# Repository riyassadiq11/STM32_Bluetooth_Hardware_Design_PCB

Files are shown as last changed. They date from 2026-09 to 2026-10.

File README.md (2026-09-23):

# STM32_Bluetooth_Hardware_Design_PCB
4‑layer PCB (49 × 24 mm, 1.6 mm) using STM32WB55CEU6 for Bluetooth. Features USB‑C with ESD protection, RF + U.FL antenna, SWD debug header, and SMPS power. Includes impedance‑controlled routing, custom footprint (DLF162500LT‑5028A1), 3D STEP models, and validated with ERC/DRC checks.

# 📡 STM32WB55 Bluetooth Hardware Design (KiCad, 4‑Layer)

## 📖 Project Overview
This project is a **4‑layer PCB design** using **STM32WB55CEU6 microcontroller** for Bluetooth communication.  
It integrates USB‑C interface, RF with U.FL antenna connector, SWD debug header, and regulated 3.3V supply.  
Custom footprints and 3D models were created to ensure accurate visualization and manufacturing readiness.

---

## 📐 PCB Specifications
- **Board size:** 49 mm × 24 mm  
- **Thickness:** 1.6 mm  
- **Layers:** 4‑layer stackup  
- **Copper Pour:**  
  - **Layer 1 (Front):** GND plane  
  - **Layer 2 (In1):** GND plane  
  - **Layer 3 (In2):** GND plane  
  - **Layer 4 (Bottom):** Power plane  
- **Impedance Control:**  
  - 50 Ω ±10% single‑ended microstrip (trace width 0.19 mm)  
  - 90 Ω ±10% differential microstrip (trace width 0.22 mm, spacing 0.15 mm)  

---

## 🔌 Schematic Explanation

### Power Supply & SMPS
- **MIC5365‑3.3 LDO regulator** converts USB 5V to 3.3V.  
- Multiple **decoupling capacitors (100nF)** placed near VDD pins.  
- **SMPS pins (VLXSMPS, SMPSLX, SMPSFB, VFBSMPS)** connected with inductors/capacitors for internal buck converter.  
- Provides efficient power delivery for RF and digital domains.
- This reduces power consumption compared to pure LDO mode.

**Working:**  
STM32WB55 uses an internal buck converter. VLXSMPS pin drives the inductor, SMPSFB senses feedback, and VFBSMPS stabilizes output.This lowers current draw and heat, especially important for battery‑powered designs.

---

### ESD Protection
- **USBLC6‑2SC6 diode array** protects USB D+ and D‑ lines.  
- Ensures compliance with USB 2.0 signal integrity while clamping high‑voltage spikes
- Prevents damage from static discharge when plugging/unplugging USB‑C.  

---

### SWD Debug Connection
- **SWD_CLK (PA14)** → Debug clock.  
- **SWD_DIO (PA13)** → Bidirectional data line.  
- **SWO (PB3)** → Trace output.  
- **NRST** → Reset line.  
- Connected via **Tag‑Connect header** for programming/debugging. 

---

### RF
- RF output routed through **matching network (L3, capacitors)**. - **DLF162500LT low‑pass filter** ensures clean 2.4–2.5 GHz band. - **U.FL coaxial connector** for external antenna.  
- Ground stitching vias improve impedance control and reduce noise.

**Working:**  
MCU generates Bluetooth RF signal → passes through matching network → filtered → sent to antenna. Impedance control (50 Ω single‑ended) ensures maximum power transfer and minimal reflection.

---

### USB‑C Interface
- USB‑C connector with **CC1/CC2 resistors** for orientation detection.  
- D+ / D‑ routed with **90 Ω differential impedance**.  
- Protected by ESD diodes.  
- VBUS feeds the LDO regulator.

---

### Peripherals
- **UART header** for communication/debugging.  
- **LED with resistor** for status indication.  
- **Push button** for Boot0/reset.  
- **Crystals:**  
  - HSE (32 MHz) → system clock.  
  - LSE (32.768 kHz) → RTC.  

---

## ✅ Design Validation
- **ERC check:** Successfully completed for schematic (no electrical rule errors).  
- **DRC check:** Successfully completed for PCB layout (no design rule violations).  

---

## ⚙️ How It Works
1. USB‑C provides 5V → LDO converts to 3.3V → SMPS stabilizes supply.  
2. MCU runs with external crystals for accurate timing.  
3. SWD header allows firmware flashing and debugging.  
4. Bluetooth RF routed through matching network + LPF → antenna.  
5. USB‑C handles data, UART header provides serial debug.  
6. ESD diodes protect USB lines, ground stitching reduces noise.  
7. LED shows status, push button controls Boot0/reset.  

---

## 🛠️ Skill Highlights
- KiCad schematic capture & 4‑layer PCB design  
- Custom footprint creation (DLF162500LT‑5028A1)  
- 3D STEP model integration (MCU, filter, crystal)  
- Impedance‑controlled routing (USB & RF)  
- SWD debug integration  
- USB‑C interface with ESD protection  
- RF matching & antenna connector design  
- ERC & DRC validation for schematic and PCB  
- Copper pour strategy (3 GND planes + 1 power plane)  
- Gerber/BOM/pick‑and‑place generation  
- Ground stitching & copper pour techniques

## Key Learnings:
- MCU & Debugging: Gained detailed knowledge of STM32WB55 pin functions, SWD interface, and MCU working principles.
- RF Engineering: Learned antenna integration, RF matching networks, and impedance‑controlled routing for Bluetooth signals.
- USB Integration: Implemented USB‑C interface with differential pair matching, controlled impedance, and ESD protection.
- Impedance Control: Calculated and applied trace width/spacing for 50 Ω single‑ended and 90 Ω differential pairs.
- PCB Stack‑Up: Understood layer stackup, core and prepreg materials (e.g., 2126), and their role in signal integrity.
- Manufacturing Readiness: Applied mounting holes, fiducial markers, and copper pour strategy (3 GND planes + 1 power plane).
- Routing Techniques: Learned via diameter selection, trace width/spacing rules, and applying specific constraints for USB and RF connections.
- Design Validation: Performed ERC and DRC checks to ensure error‑free schematic and PCB layout.

## 🖼️ Schematic

The schematic illustrates the complete STM32WB55CEU6 Bluetooth hardware design, including power supply (LDO + SMPS), USB‑C interface with ESD protection, SWD debug header, RF front‑end with matching network and U.FL antenna connector, and peripheral components (UART, LED, crystals, push button).  

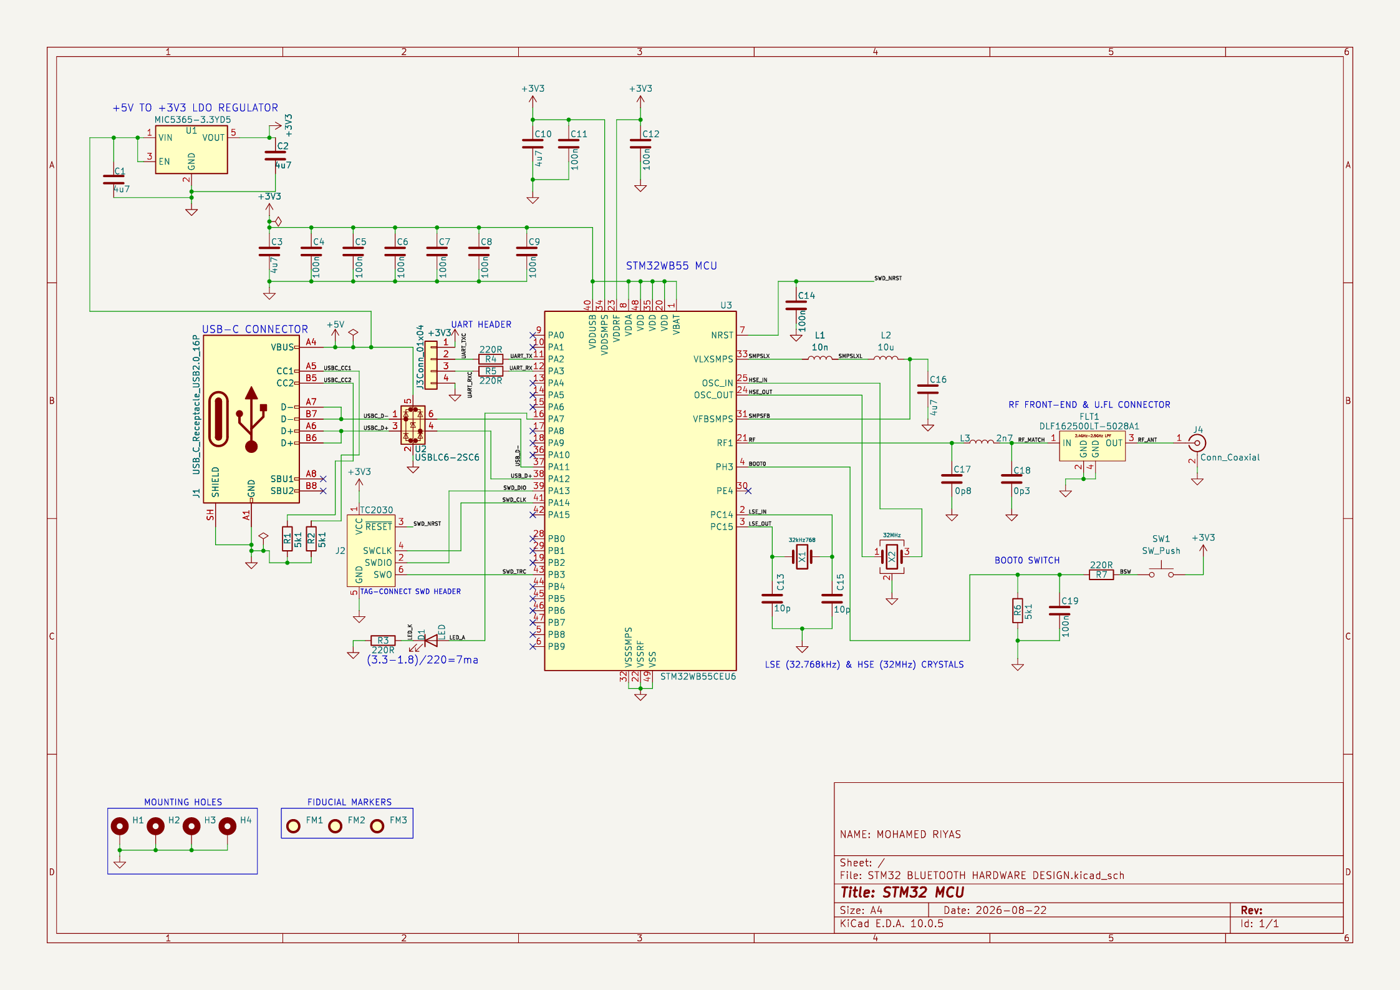
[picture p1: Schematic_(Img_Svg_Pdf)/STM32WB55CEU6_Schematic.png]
Schematic


## 🖼️ PCB Layout – Top Layer

The top layer layout shows the placement of STM32WB55CEU6, USB‑C connector, RF front‑end, SWD header, and supporting components.  
Silkscreen markings highlight pin labels and orientation for assembly.  
Copper pour on this layer is dedicated to the **GND plane**, ensuring stable return paths and reduced EMI.  

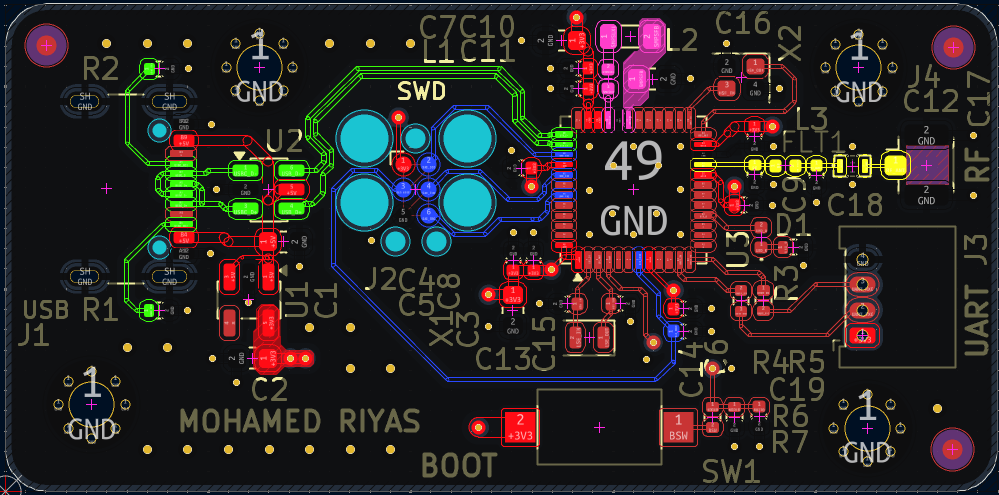
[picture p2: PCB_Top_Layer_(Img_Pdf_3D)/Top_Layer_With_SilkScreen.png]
Top Layer


## 🖼️ PCB Layout – Bottom Layer

The bottom layer layout highlights the routing of power planes and supporting traces.  
This layer is dedicated to the **power plane**, ensuring stable distribution of 3.3V and other supply rails across the board.  
It complements the three GND planes (Front, In1, In2) by providing a clean separation of power and ground, improving signal integrity and reducing noise.  

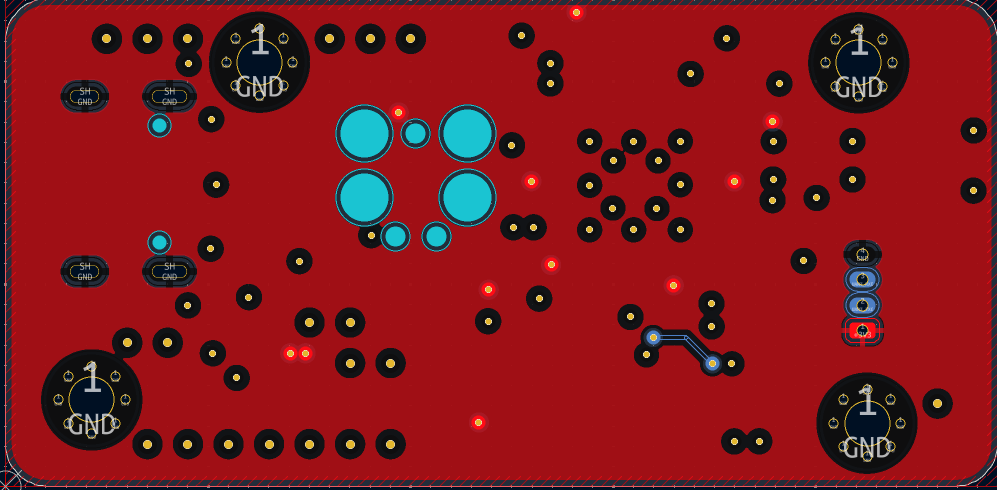
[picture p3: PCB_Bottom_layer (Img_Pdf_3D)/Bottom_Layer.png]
Bottom Layer


## 🖼️ 3D Views

The 3D views provide a realistic visualization of the PCB assembly.  
They include custom **STEP models** for the STM32WB55CEU6 microcontroller, the DLF162500LT‑5028A1 RF filter, and the 32.768 kHz crystal.  
These models ensure accurate mechanical alignment, proper component clearance, and a professional preview of the final board.  

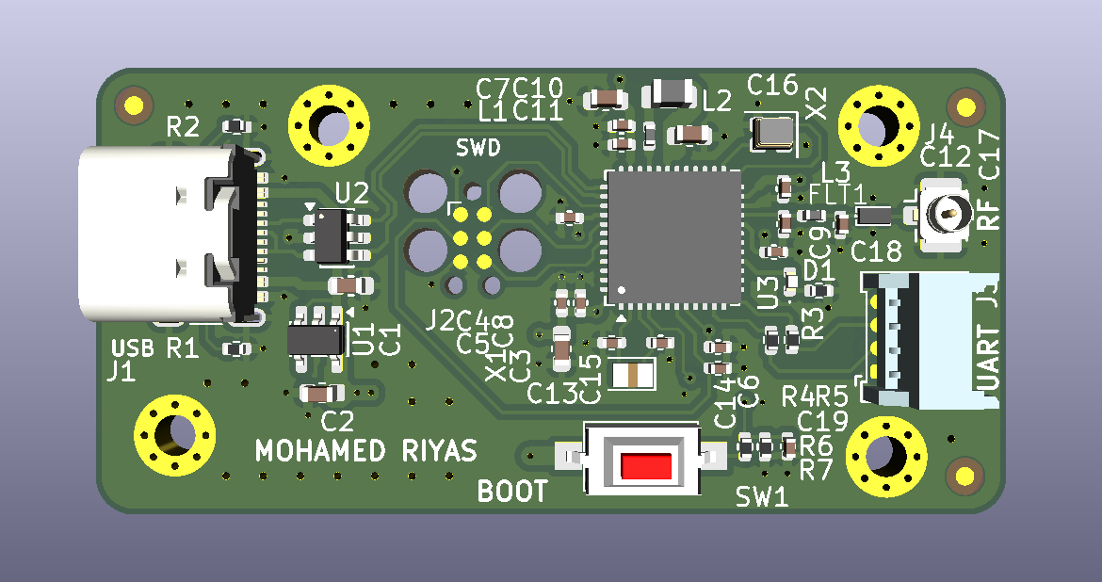
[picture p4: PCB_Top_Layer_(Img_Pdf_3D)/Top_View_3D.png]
3D Top View
  
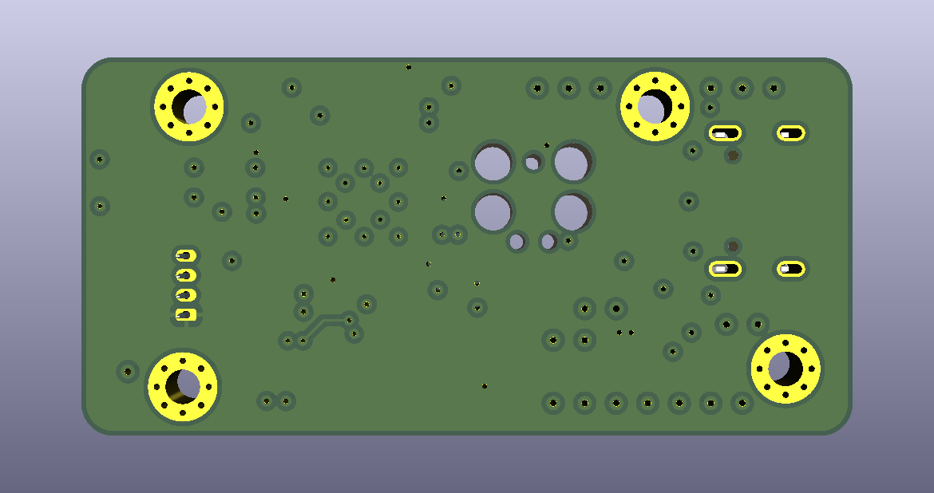
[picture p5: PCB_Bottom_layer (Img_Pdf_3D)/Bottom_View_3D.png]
3D Bottom View


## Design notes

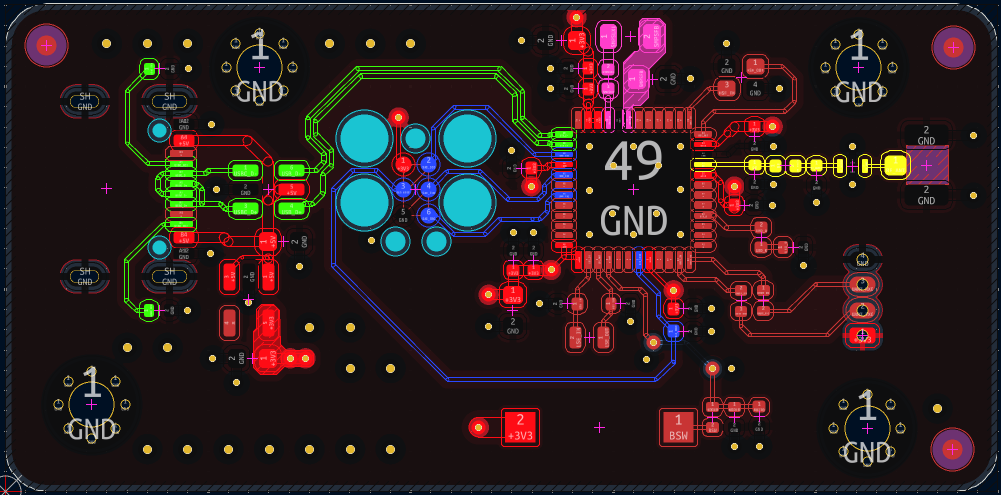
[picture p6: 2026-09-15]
Top&Bottom_Merged_Layer_(Img_Pdf)/Top&Bottom_Without_SilkScreen.png

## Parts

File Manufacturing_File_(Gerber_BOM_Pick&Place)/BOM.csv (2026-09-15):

Reference | Qty | Value | Footprint | Datasheet | Manufacturer | Manufatcurer Part Number | Distributer Link
C1,C2,C3,C10,C16 | 5 | 4u7 | Capacitor_SMD:C_0603_1608Metric |  | KYOCERA AVX | 0603YD475MAT2A | https://www.mouser.in/en/c/?q=0603YD475MAT2A
C4,C5,C6,C7,C8,C9,C11,C12,C14,C19 | 10 | 100n | Capacitor_SMD:C_0402_1005Metric |  | KYOCERA AVX | 04023C104KAT2A | https://www.mouser.in/en/c/?q=04023C104KAT2A
C13,C15 | 2 | 10p | Capacitor_SMD:C_0402_1005Metric |  | KYOCERA AVX | 04025A100JAT4A | https://www.mouser.in/en/c/?q=04025A100JAT4A
C17 | 1 | 0p8 | Capacitor_SMD:C_0402_1005Metric |  | Murata Electronics | GRM1555C1HR80BA01D | https://www.mouser.in/en/c/?q=GRM1555C1HR80BA01D
C18 | 1 | 0p3 | Capacitor_SMD:C_0402_1005Metric |  | Murata Electronics | GRM1555C1HR30WA01D | https://www.mouser.in/en/ProductDetail/Murata-Electronics/GRM1555C1HR30WA01D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
D1 | 1 | LED | LED_SMD:LED_0402_1005Metric |  | Wurth Elektronik | 150040RS73240 | https://www.mouser.in/en/ProductDetail/Wurth-Elektronik/150040RS73240?qs=8Aam6%252B7C6HGMiInmnlrBiw%3D%3D
FLT1 | 1 | DLF162500LT-5028A1 | STM32 BLUETOOTH HARDWARE DESIGN_PCBFootprints:DLF162500LT-5028A1 |  | TDK | DLF162500LT-5028A1 | https://www.mouser.in/en/ProductDetail/TDK/DLF162500LT-5028A1?qs=U%2FZX79kHR%2FlwIbAISCs3qA%3D%3D
J3 | 1 | Conn_01x04 | Connector_Molex:Molex_PicoBlade_53048-0410_1x04_P1.25mm_Horizontal |  | Molex | 53048-0410 | https://www.mouser.in/en/ProductDetail/Molex/53048-0410?qs=359VwiUTsp2msj5Tobchuw%3D%3D
J4 | 1 | Conn_Coaxial | Connector_Coaxial:U.FL_Hirose_U.FL-R-SMT-1_Vertical |  | Hirose Connector | U.FL-R-SMT(01) | https://www.mouser.in/en/c/?q=U.FL-R-SMT%2801%29
L1 | 1 | 10n | Inductor_SMD:L_0402_1005Metric |  | Murata Electronics | LQG15WZ10NJ02D | https://www.mouser.in/en/ProductDetail/Murata-Electronics/LQG15WZ10NJ02D?qs=60uY6ySkanT1eJ7IaeAl%2Fg%3D%3D
L2 | 1 | 10u | Inductor_SMD:L_0805_2012Metric |  | Murata Electronics | LQM21FN100M70L | https://www.mouser.in/en/ProductDetail/Murata-Electronics/LQM21FN100M70L?qs=8M15sSGRUn%252BogwBrvQUwLA%3D%3D
L3 | 1 | 2n7 | Inductor_SMD:L_0402_1005Metric |  | Murata Electronics | LQG15HS2N7S02D | https://www.mouser.in/en/ProductDetail/Murata-Electronics/LQG15HS2N7S02D?qs=ctz47l0uL1AKrLI74yO5Qw%3D%3D
R1,R2,R6 | 3 | 5k1 | Resistor_SMD:R_0402_1005Metric |  | YAGEO | RC0603FR-075K1L | https://www.mouser.in/en/c/?q=RC0603FR-075K1L
R3,R4,R5,R7 | 4 | 220R | Resistor_SMD:R_0402_1005Metric |  | YAGEO | RC0402FR-07221RL | https://www.mouser.in/en/ProductDetail/YAGEO/RC0402FR-07221RL?qs=YDy31nmf64y04UoKIvC83Q%3D%3D
SW1 | 1 | SW_Push | Button_Switch_SMD:SW_SPST_CK_RS282G05A3 |  | C&K | RS-282G05A3-SM RT | https://www.mouser.in/en/ProductDetail/CK/RS-282G05A3-SM-RT?qs=T%252BgPUmif8%252BjtyA9QuPnoeg%3D%3D
X1 | 1 | 32kHz768 | Crystal:Crystal_SMD_2012-2Pin_2.0x1.2mm |  | NDK | STDMUB1-32.768K | https://www.mouser.in/en/ProductDetail/NDK/STDMUB1-32.768K?qs=Tc%252BHE9vUsnsZGGDEPnJaig%3D%3D
X2 | 1 | 32MHz | Crystal:Crystal_SMD_2016-4Pin_2.0x1.6mm |  | NDK | CS06465-32M | https://www.mouser.in/en/ProductDetail/NDK/CS06465-32M?qs=Tc%252BHE9vUsnvl87v0Cxzd7g%3D%3D
U1 | 1 | MIC5365-3.3YD5 | Package_TO_SOT_SMD:TSOT-23-5 | https://ww1.microchip.com/downloads/aemDocuments/documents/APID/ProductDocuments/DataSheets/MIC5365-6-High-Performance-Single-150mA-LDO-DS20006605A.pdf | Microchip Technology | MIC5365-3.3YD5-TR | https://www.mouser.in/en/ProductDetail/Microchip-Technology/MIC5365-3.3YD5-TR?qs=U6T8BxXiZAXzRinbbfZRrg%3D%3D
U3 | 1 | STM32WB55CEU6 | Package_DFN_QFN:QFN-48-1EP_7x7mm_P0.5mm_EP5.6x5.6mm | https://www.st.com/resource/en/datasheet/stm32wb55ce.pdf | STMicroelectronics | STM32WB55CEU6 | https://www.mouser.in/en/c/?q=STM32WB55CEU6
U2 | 1 | USBLC6-2SC6 | Package_TO_SOT_SMD:SOT-23-6 | https://www.st.com/resource/en/datasheet/usblc6-2.pdf | STMicroelectronics | USBLC6-2SC6 | https://www.mouser.in/en/c/?q=USBLC6-2SC6
J1 | 1 | USB_C_Receptacle_USB2.0_16P | Connector_USB:USB_C_Receptacle_GCT_USB4105-xx-A_16P_TopMnt_Horizontal | https://www.usb.org/sites/default/files/documents/usb_type-c.zip | GCT | USB4105-GF-A | https://www.mouser.in/en/c/?q=USB4105-GF-A

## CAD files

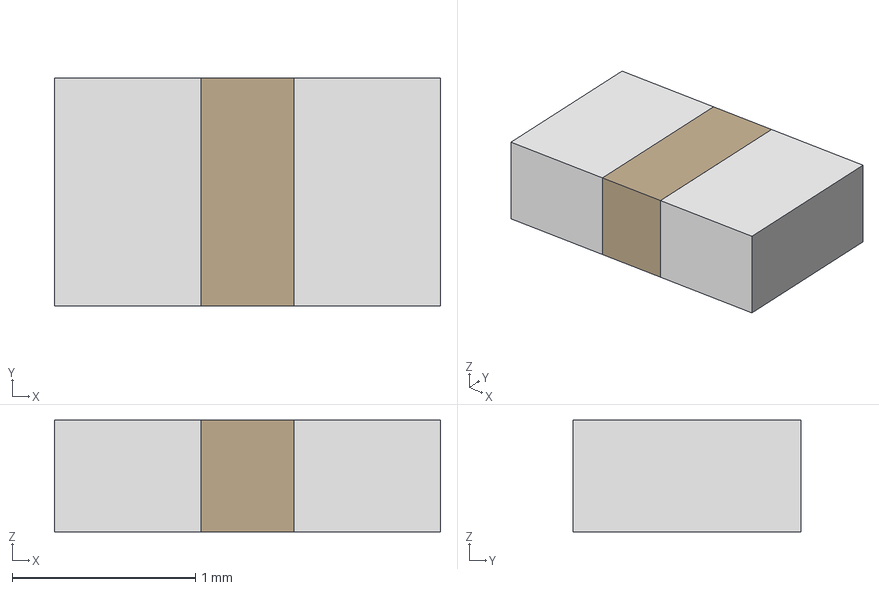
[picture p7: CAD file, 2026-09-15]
3D_Step_File/XTAL 32.768khz_NX2012SA_NDK.step
2.11 x 1.24 x 0.61 mm

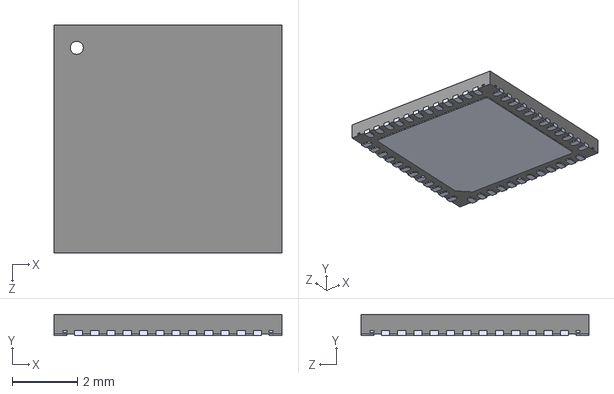
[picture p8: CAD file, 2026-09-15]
3D_Step_File/STM32WB55CEU6.STEP
7.00 x 0.65 x 7.00 mm

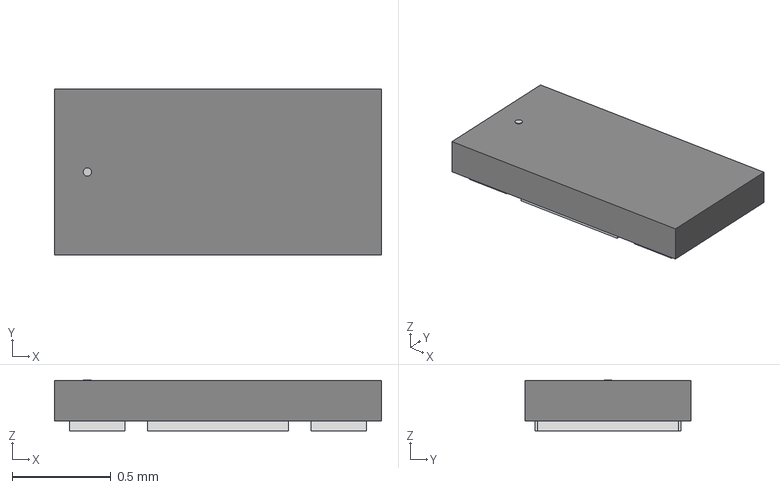
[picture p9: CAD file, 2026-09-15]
3D_Step_File/DLF-4_1P6X0P8.step
1.65 x 0.838 x 0.257 mm

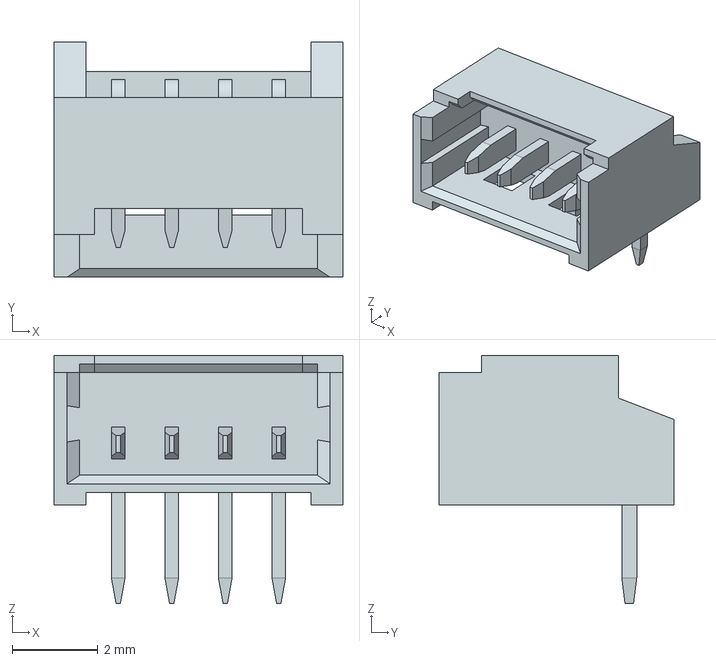
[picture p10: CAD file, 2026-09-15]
3D_Step_File/0530480410.stp
6.75 x 5.50 x 5.80 mm

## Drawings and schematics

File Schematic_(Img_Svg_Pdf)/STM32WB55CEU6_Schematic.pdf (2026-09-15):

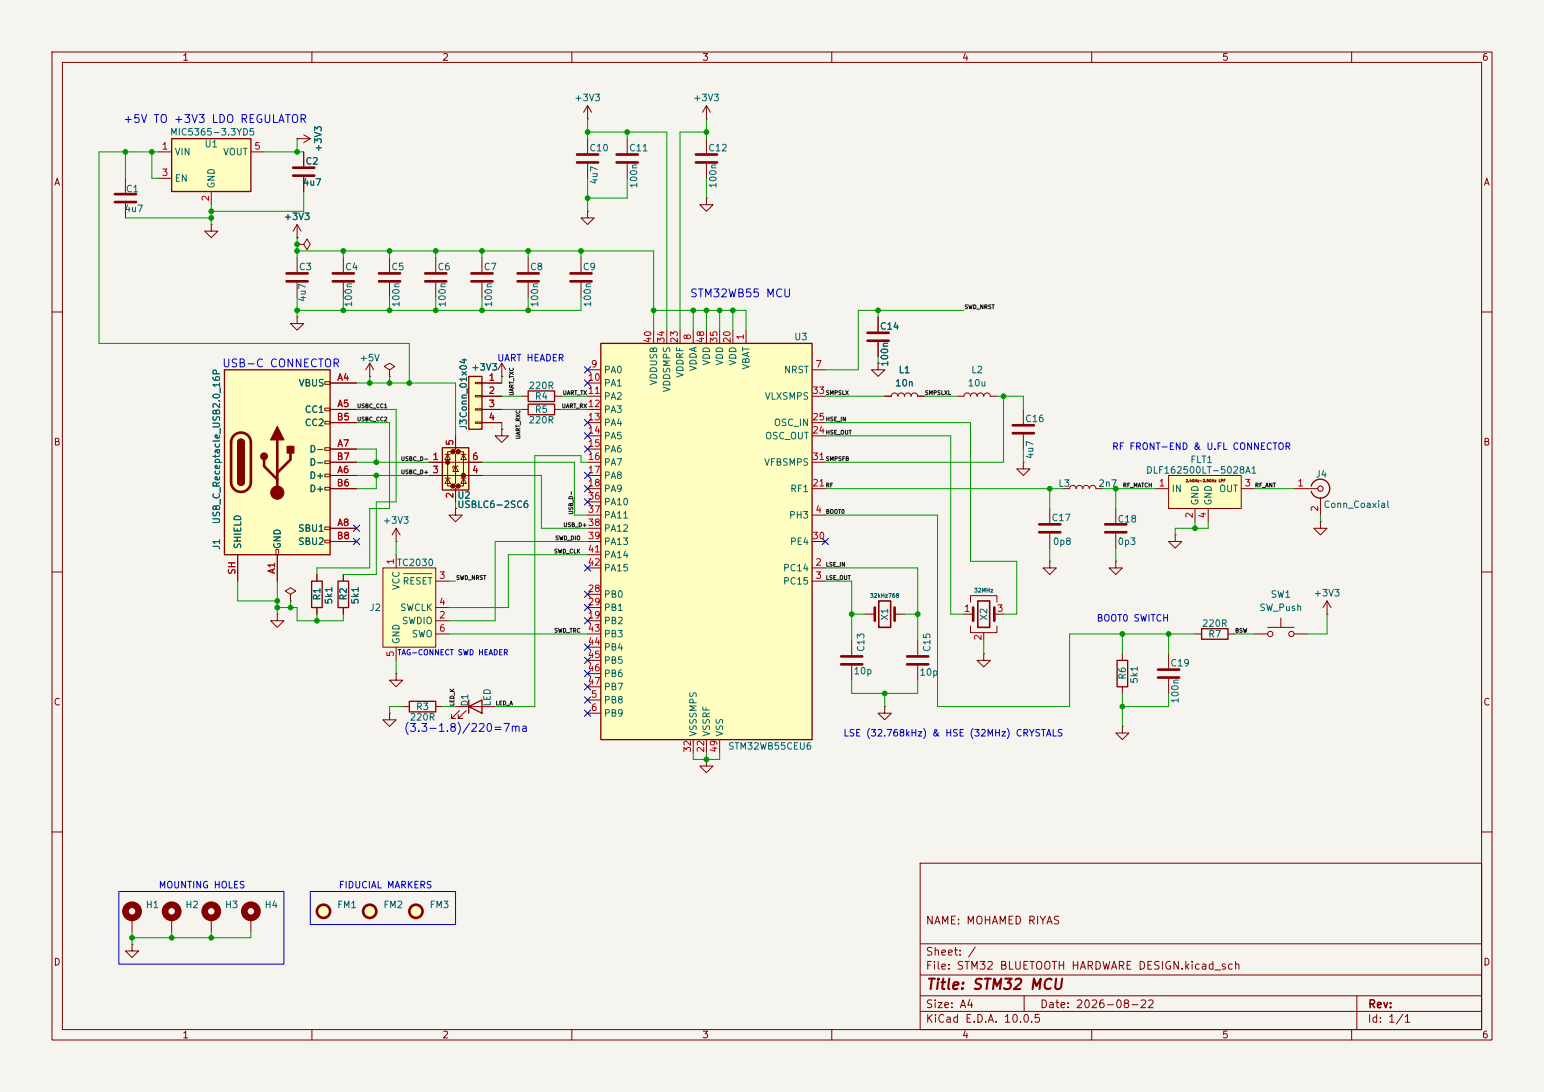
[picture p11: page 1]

RF FRONT-END & U.FL CONNECTOR +5V TO +3V3 LDO REGULATOR

LSE (32.768kHz) & HSE (32MHz) CRYSTALS UART HEADER

SWD_CLK

SWD_TRC

Sheet: /
File: STM32 BLUETOOTH HARDWARE DESIGN.kicad_sch
Title: STM32 MCU

Size: A4 | Rev:
KiCad E.D.A. 10.0.5 | Id: 1/1

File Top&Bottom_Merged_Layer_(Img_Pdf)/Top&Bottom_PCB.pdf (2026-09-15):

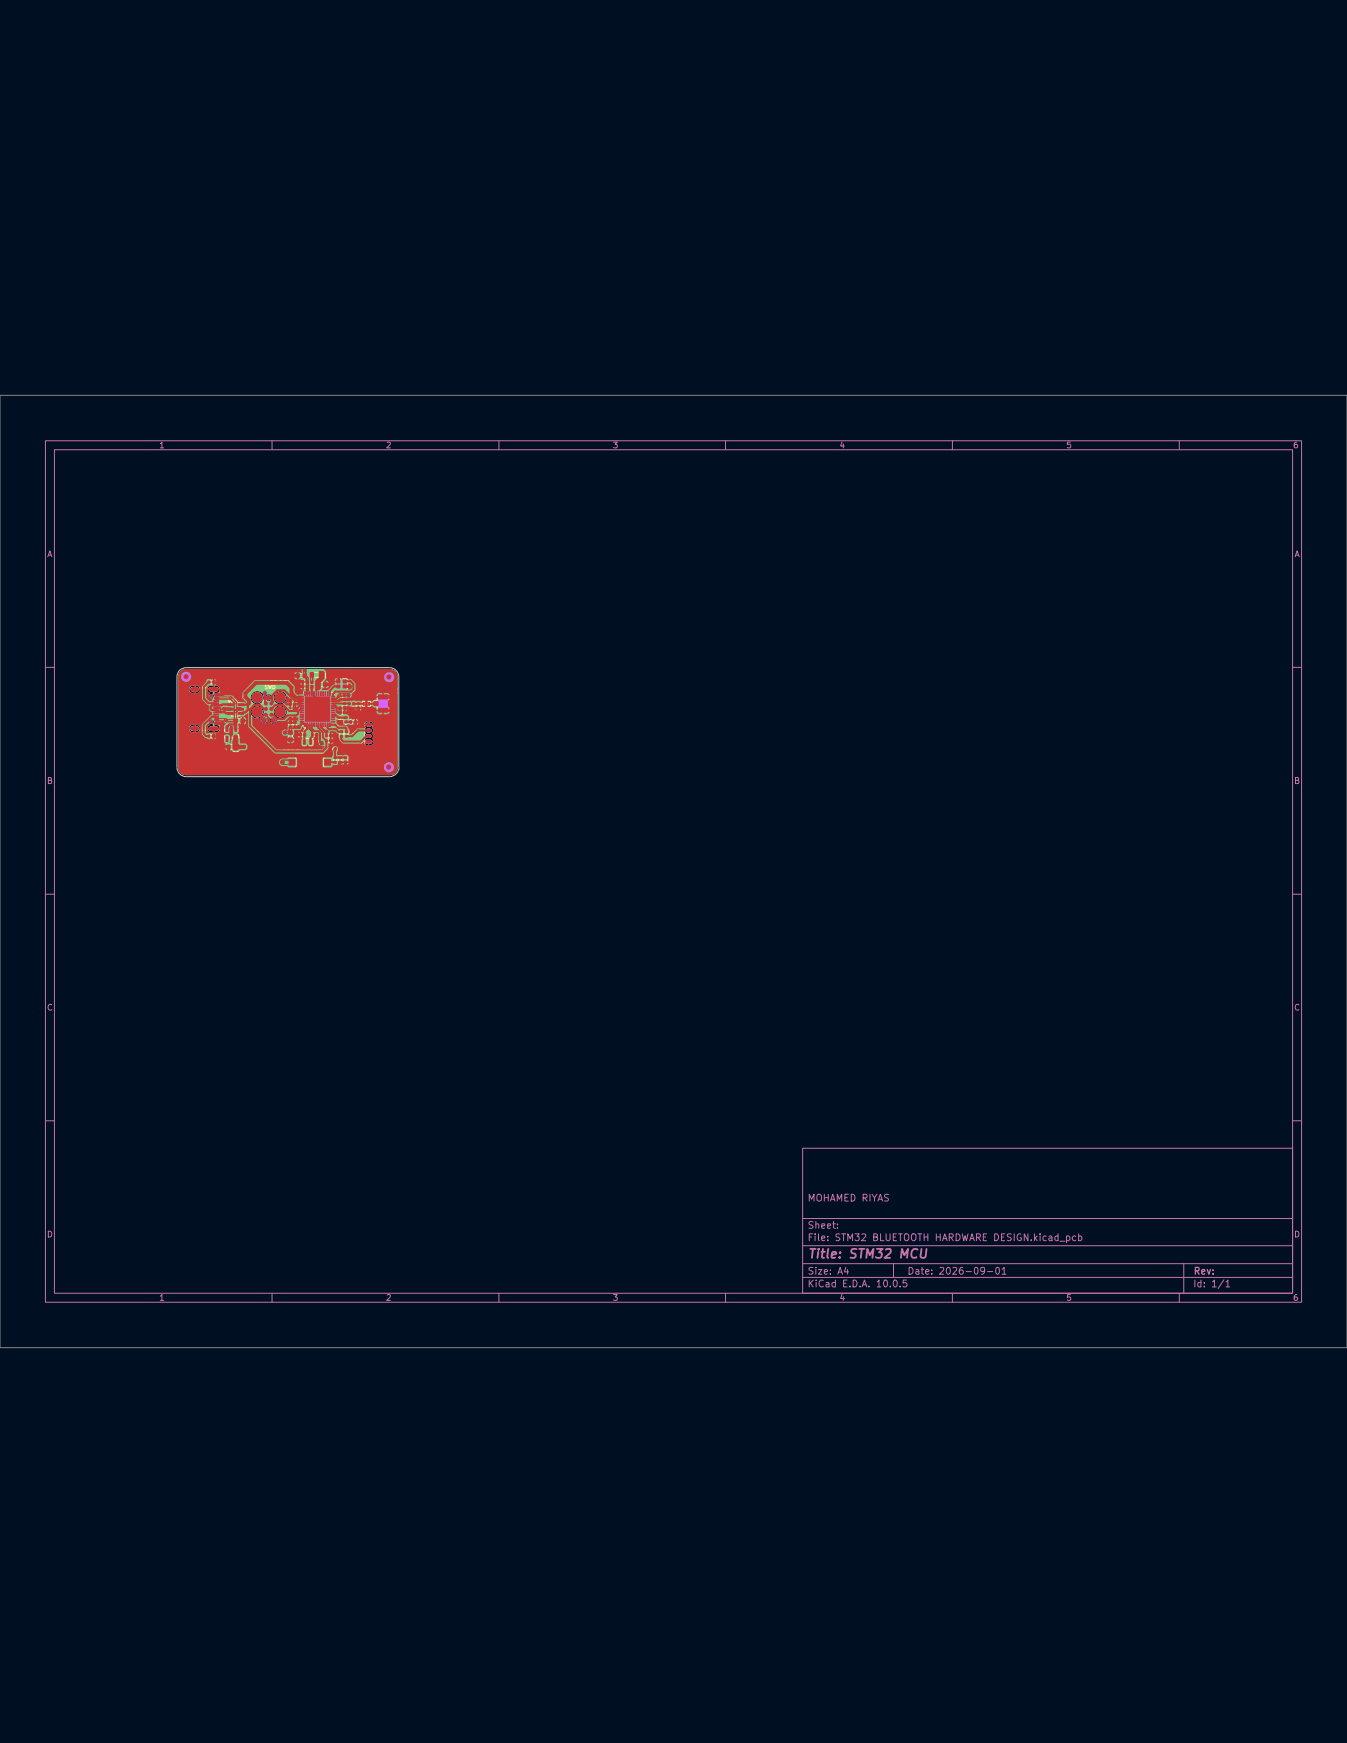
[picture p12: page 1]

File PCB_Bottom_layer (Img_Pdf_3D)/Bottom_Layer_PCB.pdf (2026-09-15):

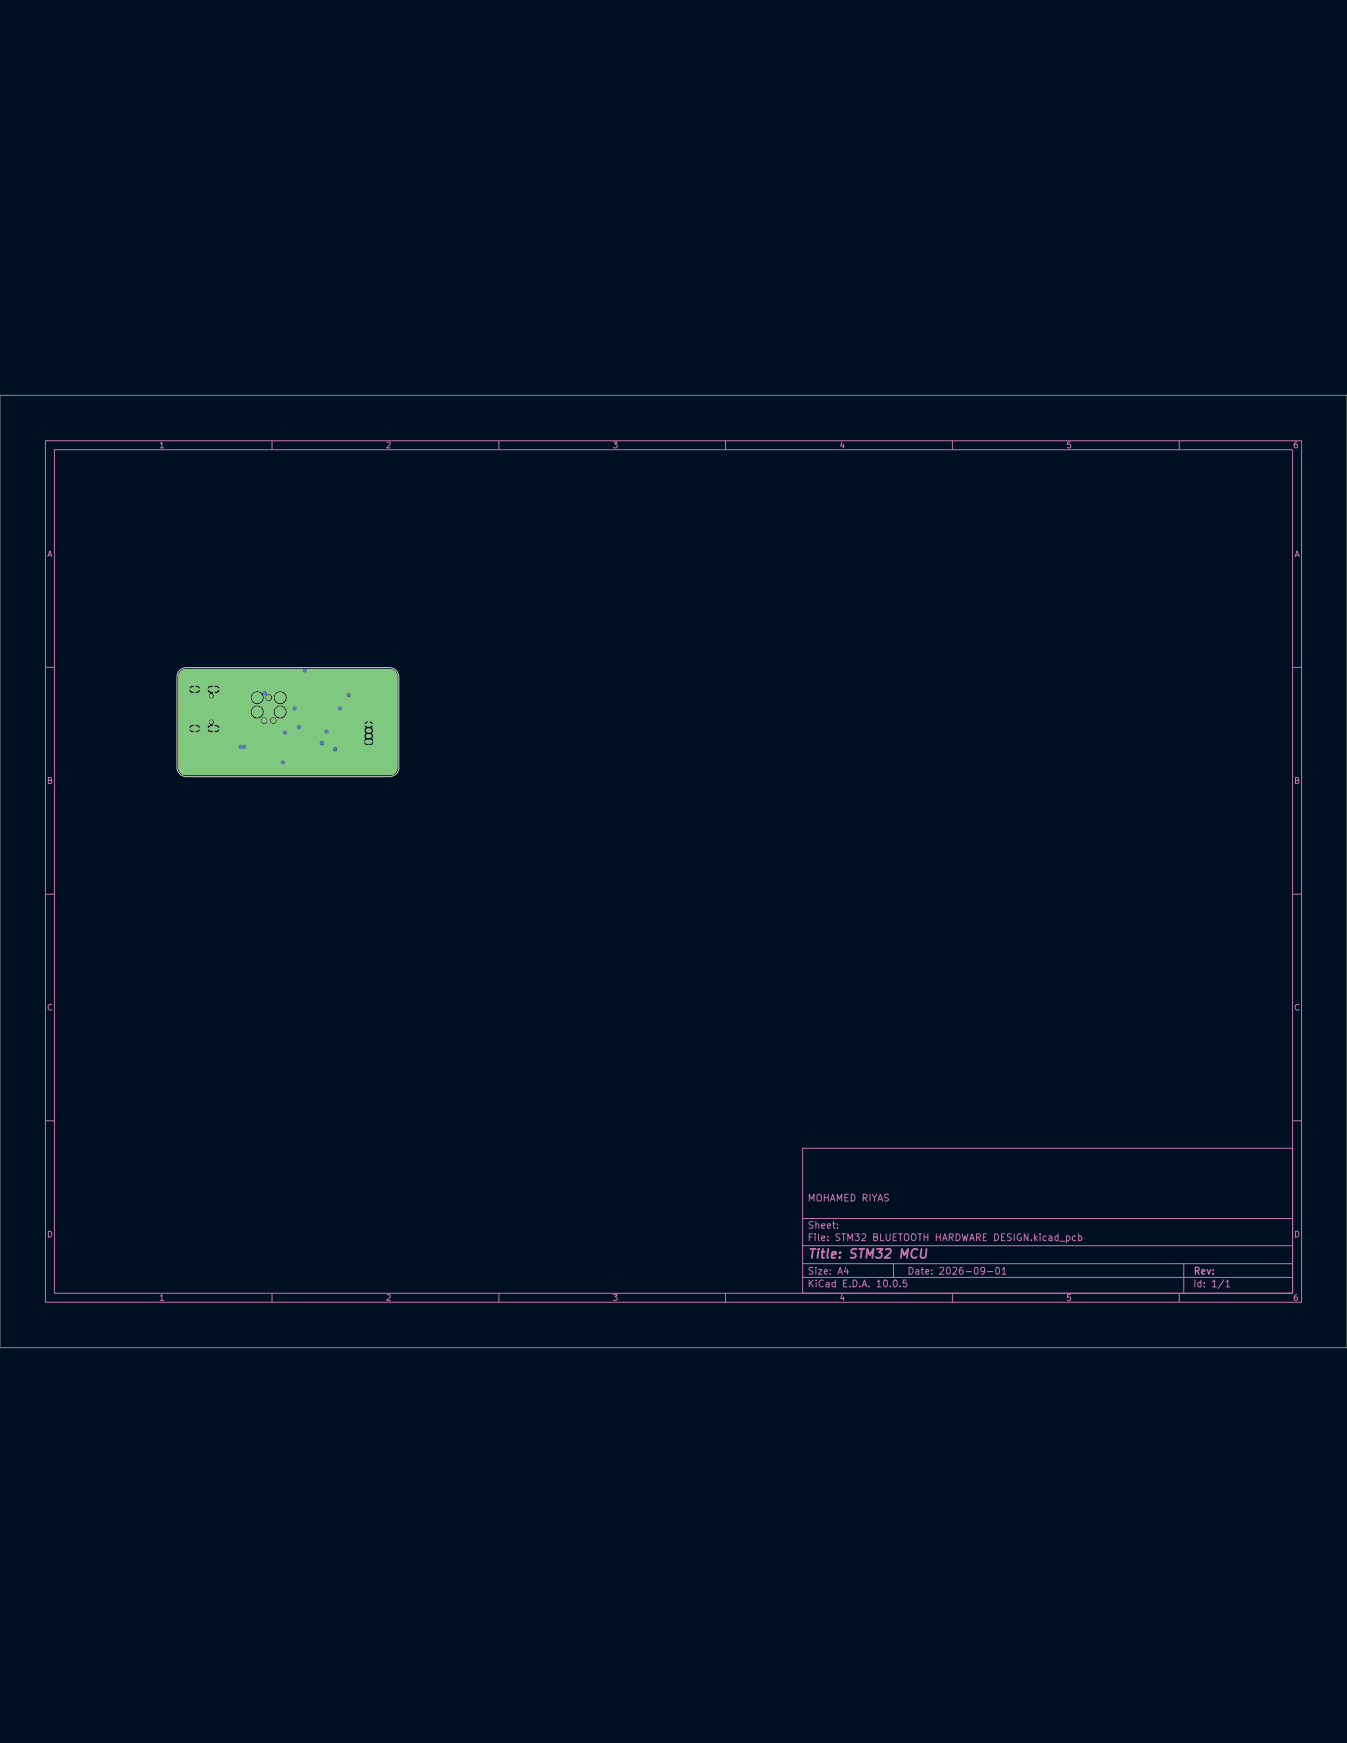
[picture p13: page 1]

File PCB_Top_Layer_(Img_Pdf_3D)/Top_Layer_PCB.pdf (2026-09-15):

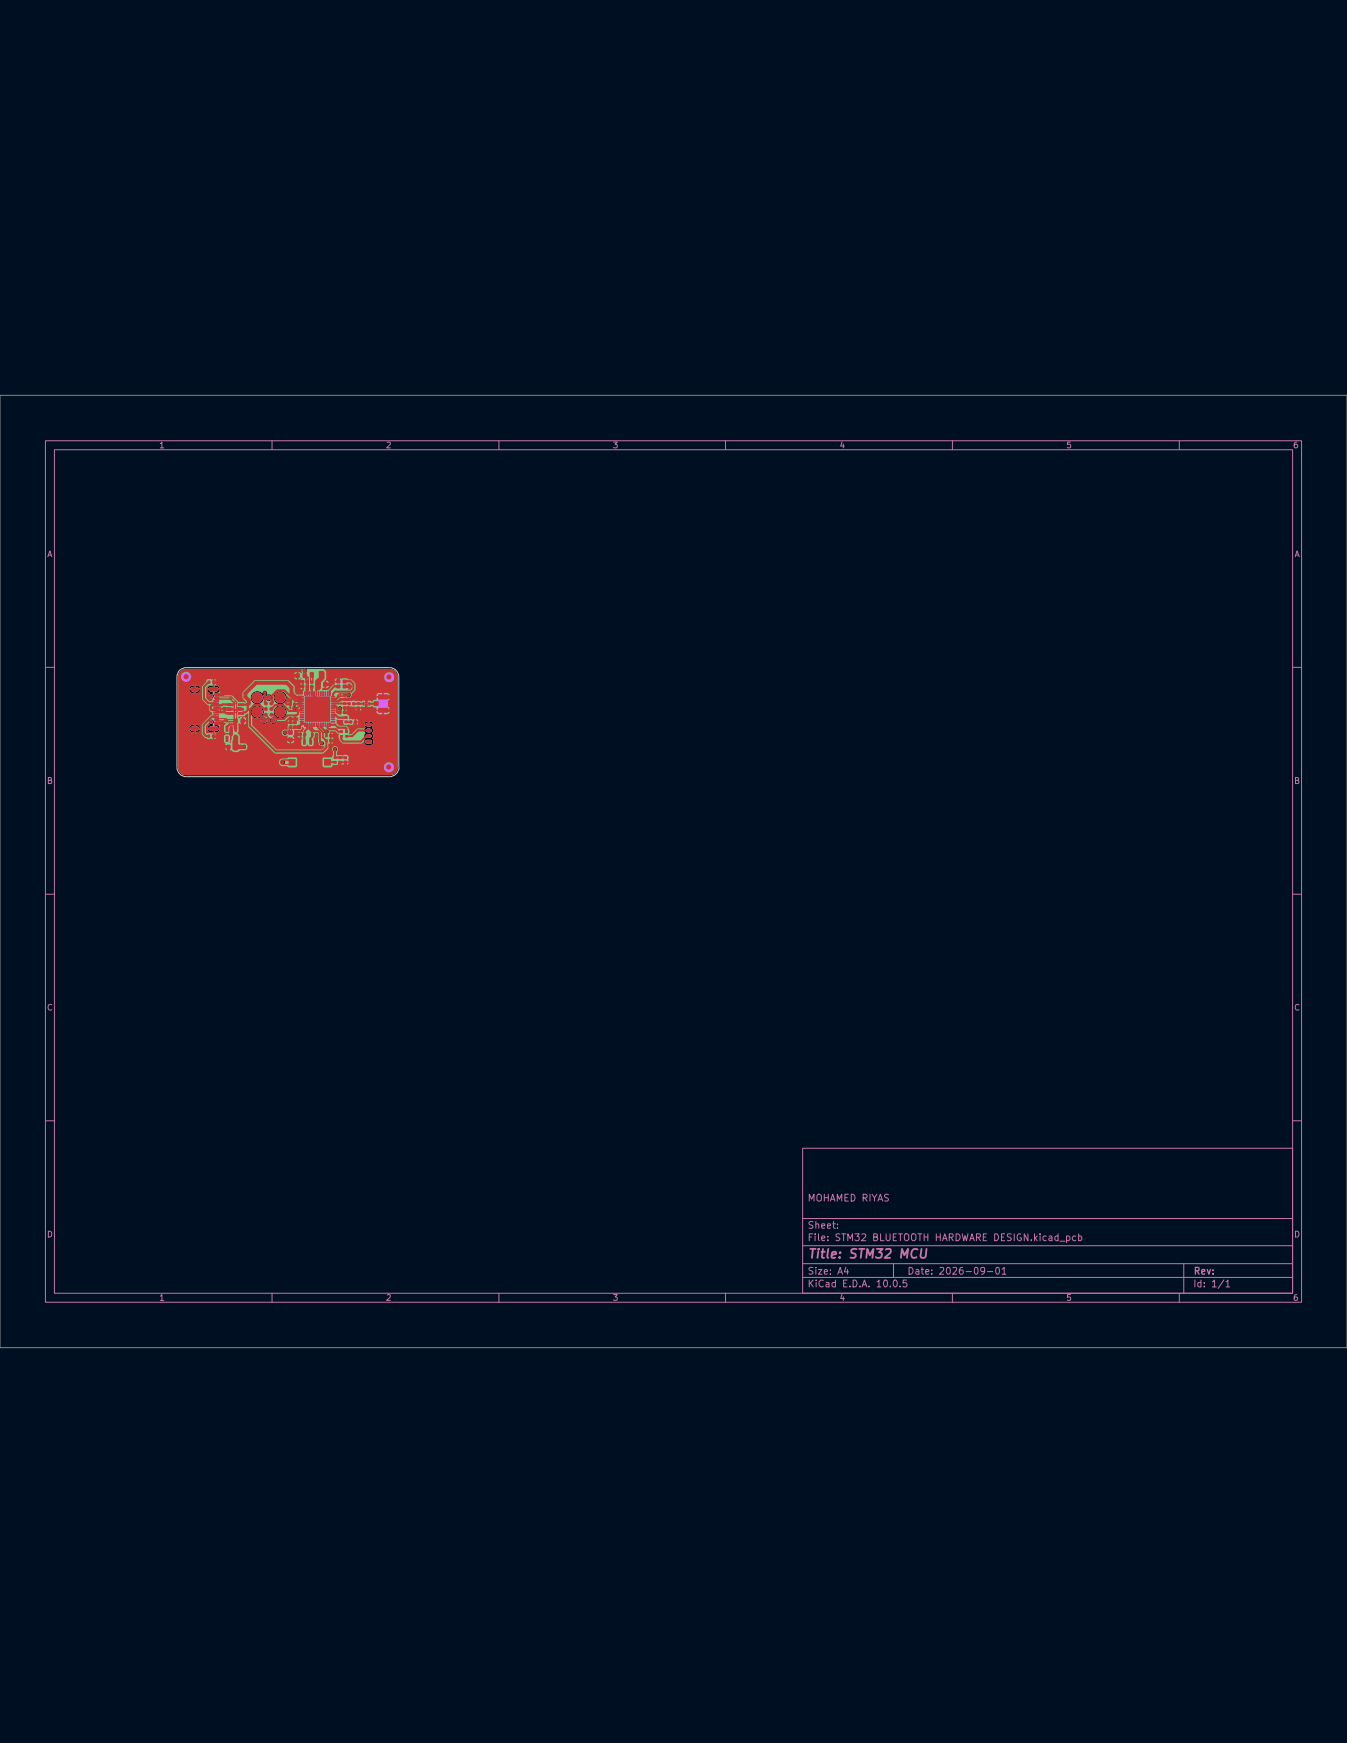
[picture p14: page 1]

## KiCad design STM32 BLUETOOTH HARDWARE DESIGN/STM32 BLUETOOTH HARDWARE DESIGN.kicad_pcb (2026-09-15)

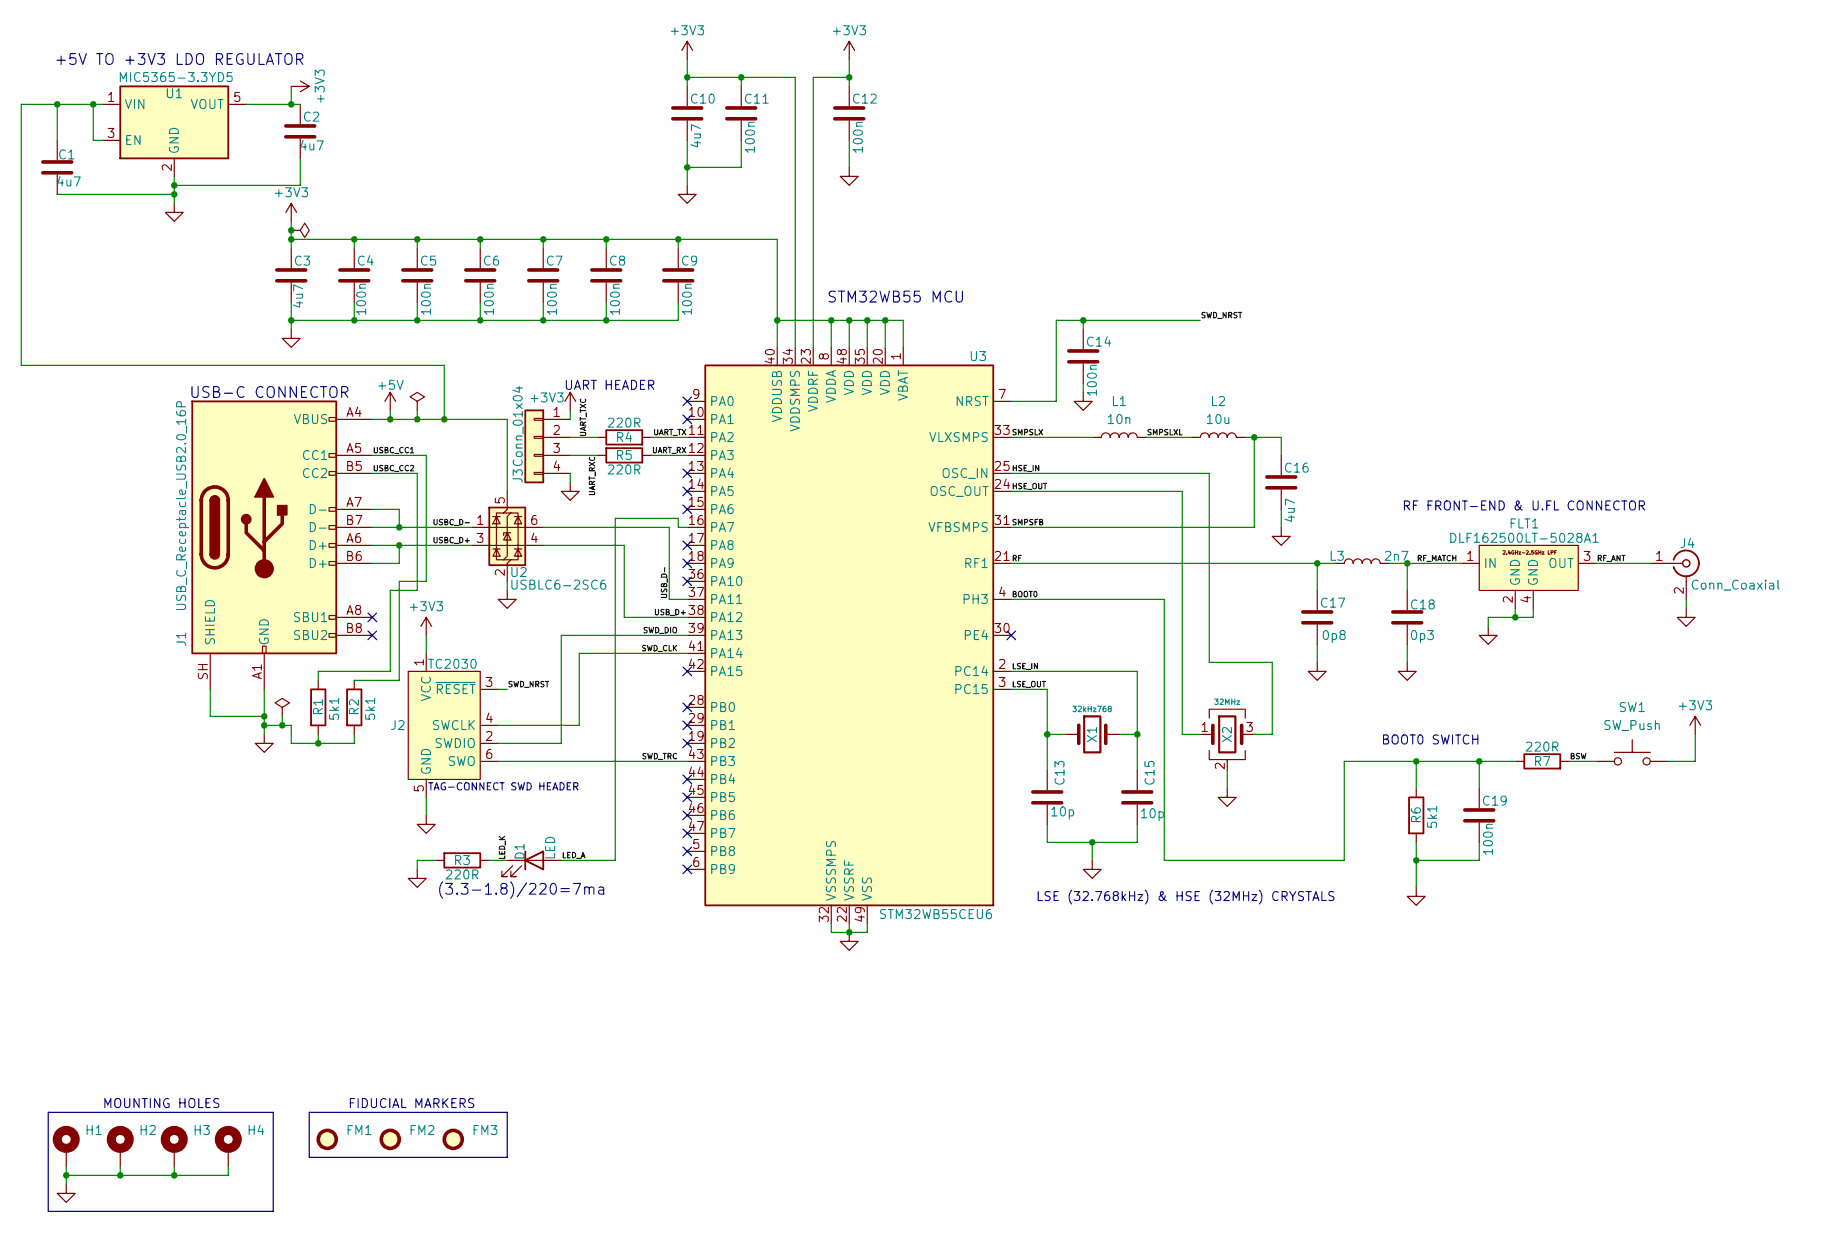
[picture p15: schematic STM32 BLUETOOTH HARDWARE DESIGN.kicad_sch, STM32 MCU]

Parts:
C1, C2, C3, C10, C16: 4u7; C_0603_1608Metric; Manufatcurer Part Number 0603YD475MAT2A
C4, C5, C6, C7, C8, C9, C11, C12, C14, C19: 100n; C_0402_1005Metric; Manufatcurer Part Number 04023C104KAT2A
C13, C15: 10p; C_0402_1005Metric; Manufatcurer Part Number 04025A100JAT4A
C17: 0p8; C_0402_1005Metric; Manufatcurer Part Number GRM1555C1HR80BA01D
C18: 0p3; C_0402_1005Metric; Manufatcurer Part Number GRM1555C1HR30WA01D
D1: LED; LED_0402_1005Metric; Manufatcurer Part Number 150040RS73240
FLT1: DLF162500LT-5028A1; Manufatcurer Part Number DLF162500LT-5028A1
FM1, FM2, FM3: Fiducial; Fiducial_1mm_Mask2mm
H1, H2, H3, H4: MountingHole_Pad; MountingHole_2.2mm_M2_Pad_Via
J1: USB_C_Receptacle_USB2.0_16P; USB_C_Receptacle_GCT_USB4105-xx-A_16P_TopMnt_Horizontal; Manufatcurer Part Number USB4105-GF-A
J2: TC2030; Tag-Connect_TC2030-IDC-FP_2x03_P1.27mm_Vertical
J3: Conn_01x04; Molex_PicoBlade_53048-0410_1x04_P1.25mm_Horizontal; Manufatcurer Part Number 53048-0410
J4: Conn_Coaxial; U.FL_Hirose_U.FL-R-SMT-1_Vertical; Manufatcurer Part Number U.FL-R-SMT(01)
L1: 10n; L_0402_1005Metric; Manufatcurer Part Number LQG15WZ10NJ02D
L2: 10u; L_0805_2012Metric; Manufatcurer Part Number LQM21FN100M70L
L3: 2n7; L_0402_1005Metric; Manufatcurer Part Number LQG15HS2N7S02D
R1, R2, R6: 5k1; R_0402_1005Metric; Manufatcurer Part Number RC0603FR-075K1L
R3, R4, R5, R7: 220R; R_0402_1005Metric; Manufatcurer Part Number RC0402FR-07221RL
SW1: SW_Push; SW_SPST_CK_RS282G05A3; Manufatcurer Part Number RS-282G05A3-SM RT
U1: MIC5365-3.3YD5; TSOT-23-5; Manufatcurer Part Number MIC5365-3.3YD5-TR
U2: USBLC6-2SC6; SOT-23-6; Manufatcurer Part Number USBLC6-2SC6
U3: STM32WB55CEU6; QFN-48-1EP_7x7mm_P0.5mm_EP5.6x5.6mm; Manufatcurer Part Number STM32WB55CEU6
X1: 32kHz768; Crystal_SMD_2012-2Pin_2.0x1.2mm; Manufatcurer Part Number STDMUB1-32.768K
X2: 32MHz; Crystal_SMD_2016-4Pin_2.0x1.6mm; Manufatcurer Part Number CS06465-32M

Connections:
+3V3: C2.1, C3.1, C4.1, C5.1, C6.1, C7.1, C8.1, C9.1, C10.1, C11.1, C12.1, J2.1 (VCC), J3.1, SW1.2, U1.5 (VOUT), U3.1 (VBAT), U3.8 (VDDA), U3.20 (VDD), U3.23 (VDDRF), U3.34 (VDDSMPS), U3.35 (VDD), U3.40 (VDDUSB), U3.48 (VDD)
+5V: C1.1, J1.A4 (VBUS), J1.A9 (VBUS), J1.B4 (VBUS), J1.B9 (VBUS), U1.1 (VIN), U1.3 (EN), U2.5 (VBUS)
/BOOT0: C19.1, R6.1, R7.1, U3.4 (PH3)
/BSW: R7.2, SW1.1
/HSE_IN: U3.25 (OSC_IN), X2.3
/HSE_OUT: U3.24 (OSC_OUT), X2.1
/LED_A: D1.2 (A), U3.16 (PA7)
/LED_K: D1.1 (K), R3.1
/LSE_IN: C15.1, U3.2 (PC14), X1.2
/LSE_OUT: C13.1, U3.3 (PC15), X1.1
/RF: C17.1, L3.1, U3.21 (RF1)
/RF_ANT: FLT1.3 (OUT), J4.1 (In)
/RF_MATCH: C18.1, FLT1.1 (IN), L3.2
/SMPSFB: C16.1, L2.2, U3.31 (VFBSMPS)
/SMPSLX: L1.1, U3.33 (VLXSMPS)
/SMPSLXL: L1.2, L2.1
/SWD_CLK: J2.4 (SWCLK), U3.41 (PA14)
/SWD_DIO: J2.2 (SWDIO), U3.39 (PA13)
/SWD_NRST: C14.1, J2.3 (~RESET), U3.7 (NRST)
/SWD_TRC: J2.6 (SWO), U3.43 (PB3)
/UART_RX: R5.1, U3.12 (PA3)
/UART_RXC: J3.3, R5.2
/UART_TX: R4.2, U3.11 (PA2)
/UART_TXC: J3.2, R4.1
/USBC_CC1: J1.A5 (CC1), R2.1
/USBC_CC2: J1.B5 (CC2), R1.1
/USBC_D+: J1.A6 (D+), J1.B6 (D+), U2.3 (I/O2)
/USBC_D-: J1.A7 (D-), J1.B7 (D-), U2.1 (I/O1)
/USB_D+: U2.4 (I/O2), U3.38 (PA12)
/USB_D-: U2.6 (I/O1), U3.37 (PA11)
GND: C1.2, C2.2, C3.2, C4.2, C5.2, C6.2, C7.2, C8.2, C9.2, C10.2, C11.2, C12.2, C13.2, C14.2, C15.2, C16.2, C17.2, C18.2, C19.2, FLT1.2 (GND), FLT1.4 (GND), H1.1 (1_1), H2.1 (1_1), H3.1 (1_1), H4.1 (1_1), J1.A1 (GND), J1.A12 (GND), J1.B1 (GND), J1.B12 (GND), J1.SH (SHIELD), J2.5 (GND), J3.4, J4.2 (Ext), R1.2, R2.2, R3.2, R6.2, U1.2 (GND), U2.2 (GND), U3.22 (VSSRF), U3.32 (VSSSMPS), U3.49 (VSS), X2.2 (G), X2.4 (G)

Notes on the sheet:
STM32WB55 MCU
LSE (32.768kHz) & HSE (32MHz) CRYSTALS
BOOT0 SWITCH
(3.3-1.8)/220=7ma
FIDUCIAL MARKERS
UART HEADER
RF FRONT-END & U.FL CONNECTOR
MOUNTING HOLES
USB-C CONNECTOR
+5V TO +3V3 LDO REGULATOR
TAG-CONNECT SWD HEADER

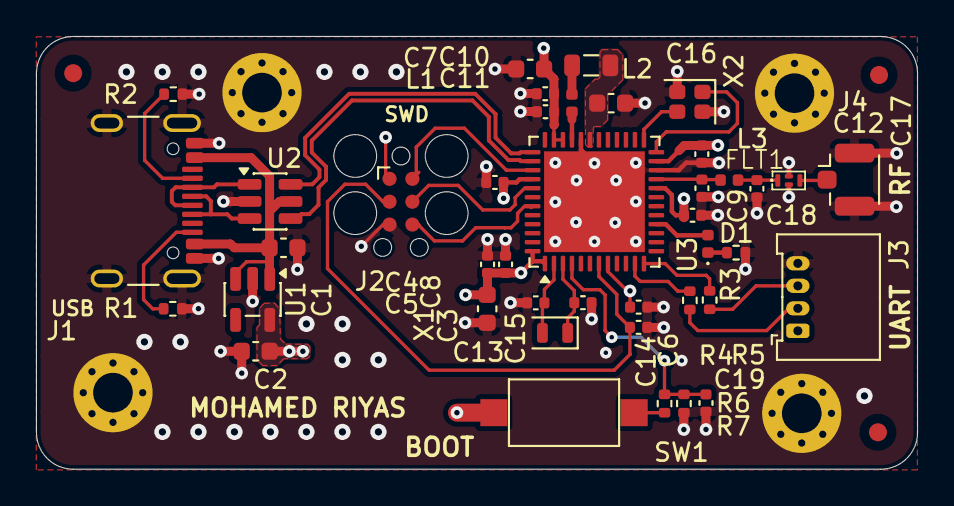
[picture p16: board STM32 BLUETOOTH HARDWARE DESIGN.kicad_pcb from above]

Board: 4 copper layers, 49.0 x 24.0 mm, 48 parts (0 on the bottom side), 31 nets.

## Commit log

2026-09-15 Enhance README with project details and specifications
    Added detailed project overview, specifications, and explanations for the STM32WB55 Bluetooth hardware design.
2026-09-15 KiCad Project file
    [0530480410.stp, STM32 BLUETOOTH HARDWARE DESIGN.kicad_pcb, STM32 BLUETOOTH HARDWARE DESIGN.kicad_sch]
2026-09-15 Manufacturing File
    [BOM.csv]
2026-09-15 Customized Footprints
2026-09-15 Step File
    [DLF-4_1P6X0P8.step, STM32WB55CEU6.STEP, XTAL 32.768khz_NX2012SA_NDK.step]
2026-09-15 Add schematic section to README
    Added schematic section with image and description.
2026-09-15 Add PCB Layout section for top layer
    Added PCB layout section for the top layer with details.
2026-09-15 Add PCB Layout section for Bottom Layer
    Added section for PCB layout of the bottom layer, detailing power plane routing and supply distribution.
2026-09-15 Add 3D views section to README
    Added section for 3D views of PCB assembly with images.
2026-11-08 Replace PCB layout images in README
    Updated images for top and bottom layer PCB layouts in README.
2026-11-08 Update Layer 1 description from GND to Signal
